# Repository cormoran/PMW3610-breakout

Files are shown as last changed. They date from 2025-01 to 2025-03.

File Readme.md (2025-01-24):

My PMW3610 breakout board collections and kicad library

- [V1](kicad_projects/PMW3610-breakout-v1/Readme.md)
  - Designed to minimize 1 side length (14mm x 21mm)
- [V2](kicad_projects/PMW3610-breakout-v2/Readme.md)
  - Designed to minimize width + height (17.6mm x 16.6mm)
  - Designed for 1 layer PCB assembly
  - 1.8V support by default. 3.6V support by manually soldering LDO.
- [V3](kicad_projects/PMW3610-breakout-v3/Readme.md) (I've not assembled yet!)
  - Designed to minimize width + height (17.6mm x 16.6mm)
  - Designed for 1 layer PCB assembly
  - 3.6V support by default. 1.8V support by removing LDO.

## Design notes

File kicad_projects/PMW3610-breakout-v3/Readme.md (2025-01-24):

## PMW3610 breakout board (v3)

I've not assembled this design yet. Functionality is not confirmed yet!

動作未確認

Features

- width = 17.6mm
- height = 16.6mm
- Designed for 100% 1-layer PCB assembly
- 3.6V support by default
- 1.8V support by removing LDO
- 6pin 5mm pitch FFC
- Test pad

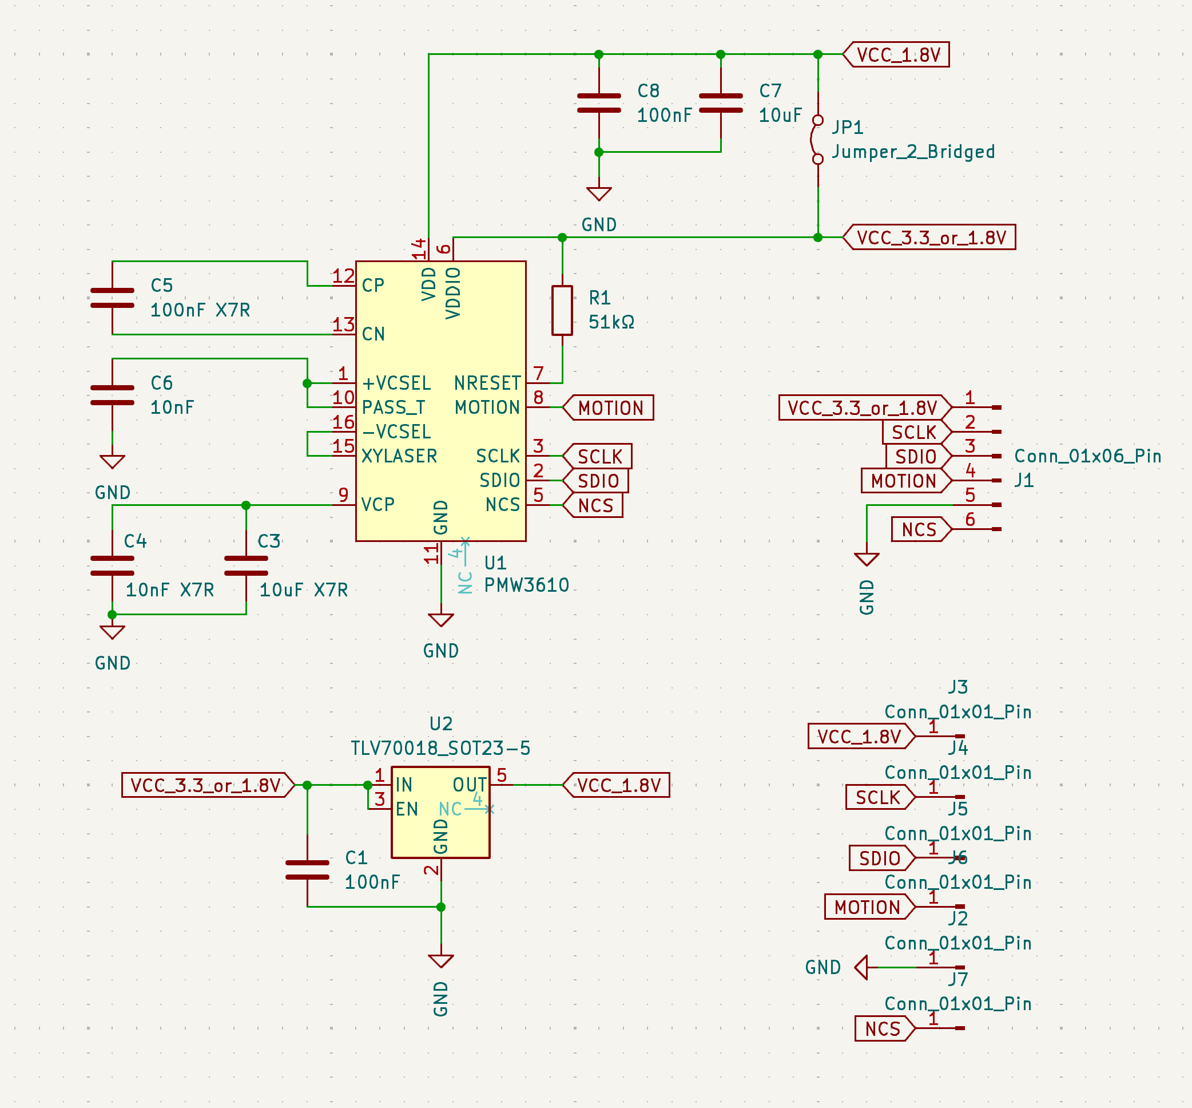
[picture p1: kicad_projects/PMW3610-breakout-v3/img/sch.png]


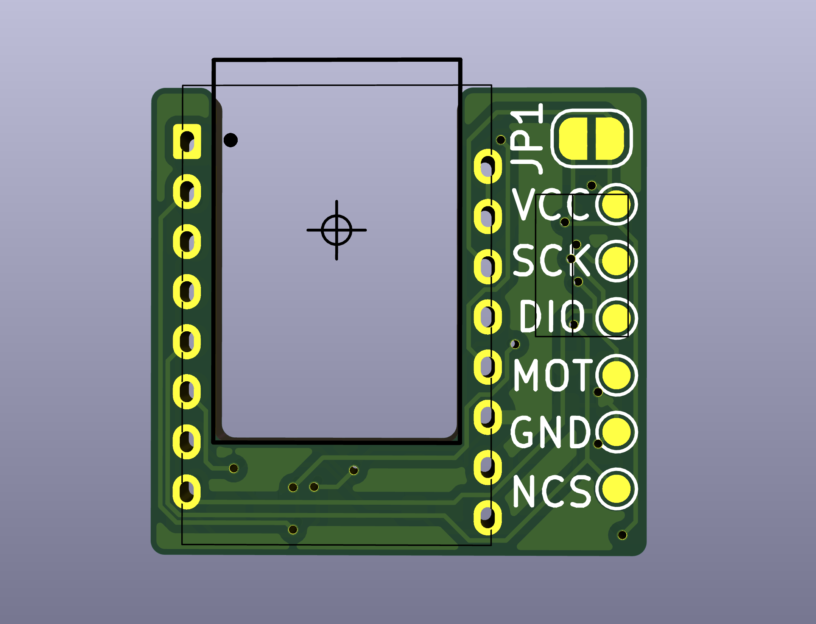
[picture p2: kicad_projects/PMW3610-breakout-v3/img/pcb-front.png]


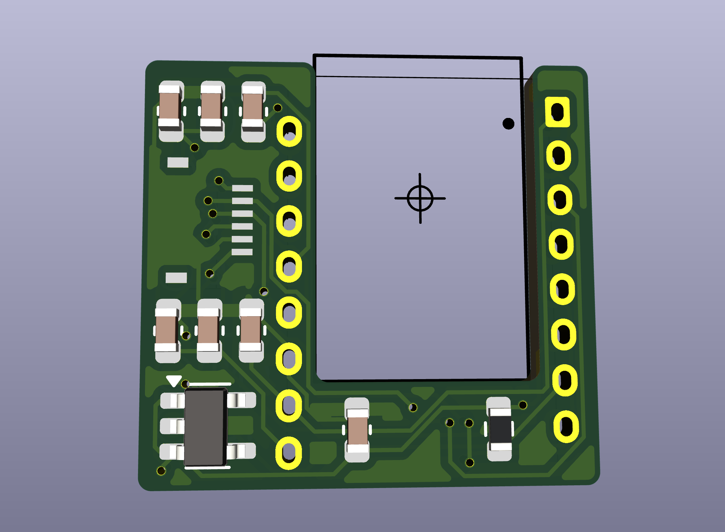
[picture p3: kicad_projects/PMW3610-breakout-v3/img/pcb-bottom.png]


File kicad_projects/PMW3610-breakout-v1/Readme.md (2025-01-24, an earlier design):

## PMW3610 breakout board (v1)

Features

- width = **14mm** (by cutting mounting holes)
- height = 21mm (by cutting mounting holes)
- 3.6V support
- 6pin 5mm pitch FFC

Problems

- Requires high manual soldering skills
- Unstable due to LDO's poor transient response?
  - It got stable by replacing C2 to 10uF in my case

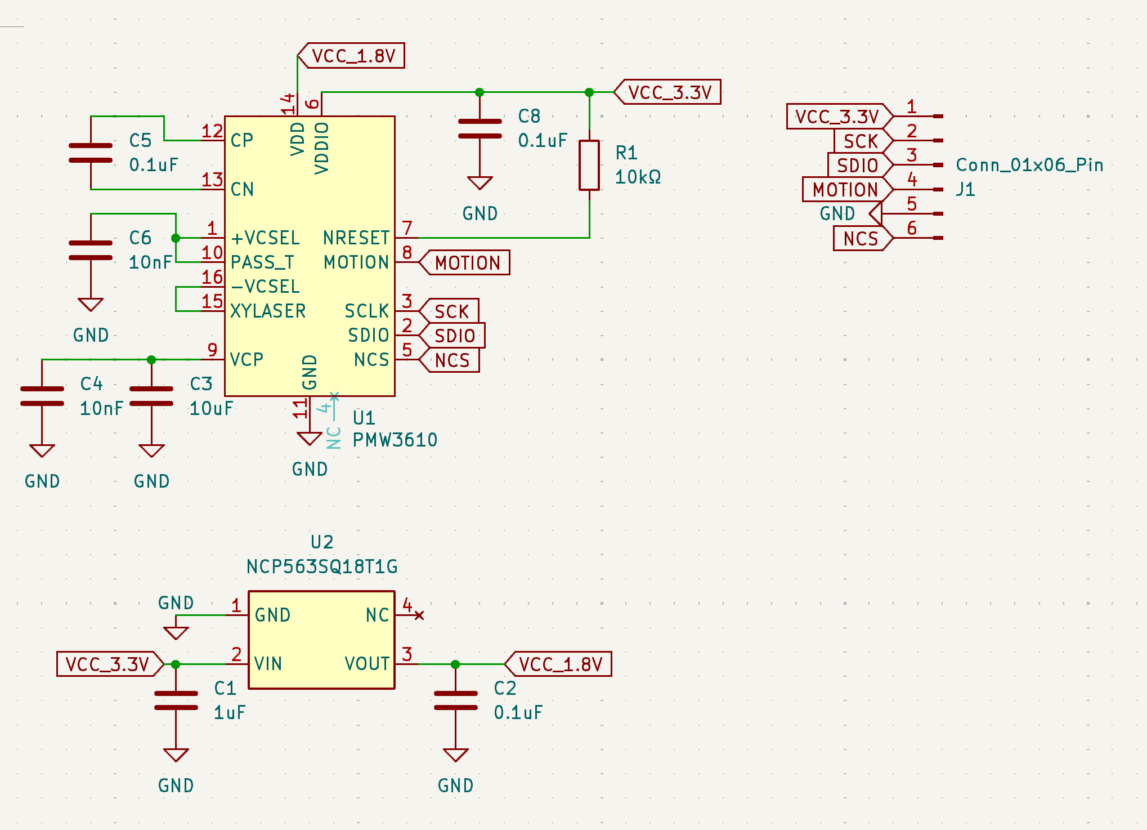
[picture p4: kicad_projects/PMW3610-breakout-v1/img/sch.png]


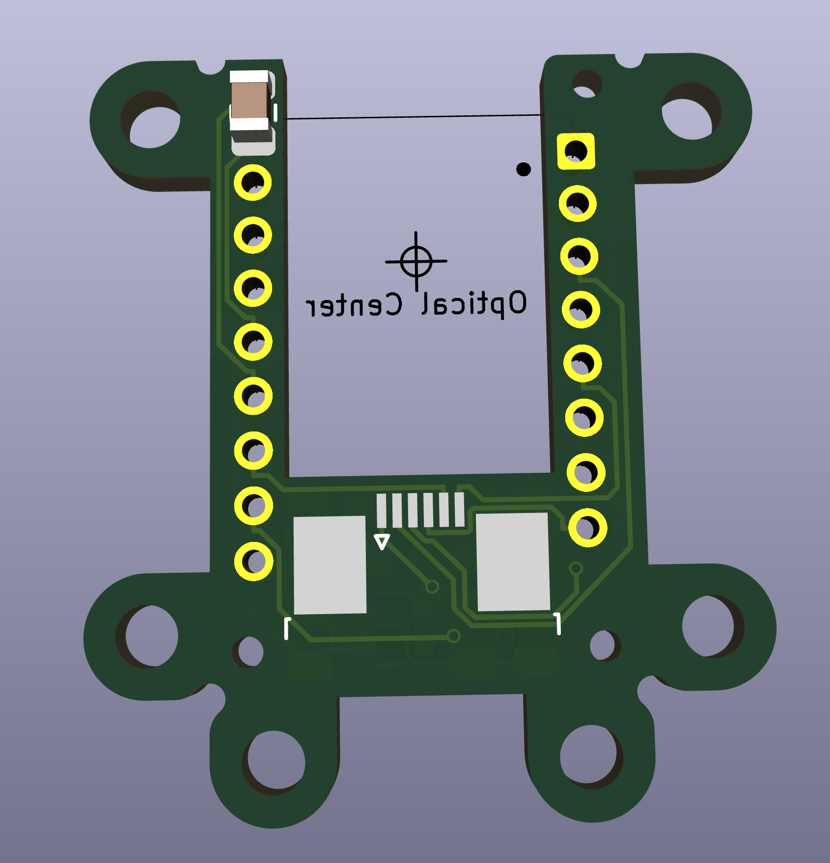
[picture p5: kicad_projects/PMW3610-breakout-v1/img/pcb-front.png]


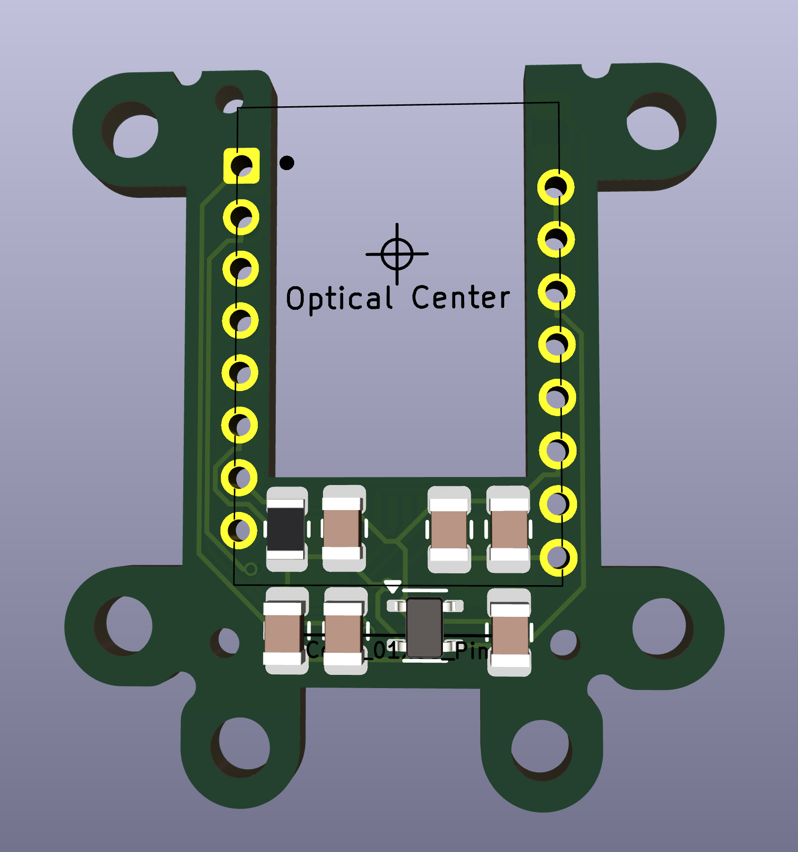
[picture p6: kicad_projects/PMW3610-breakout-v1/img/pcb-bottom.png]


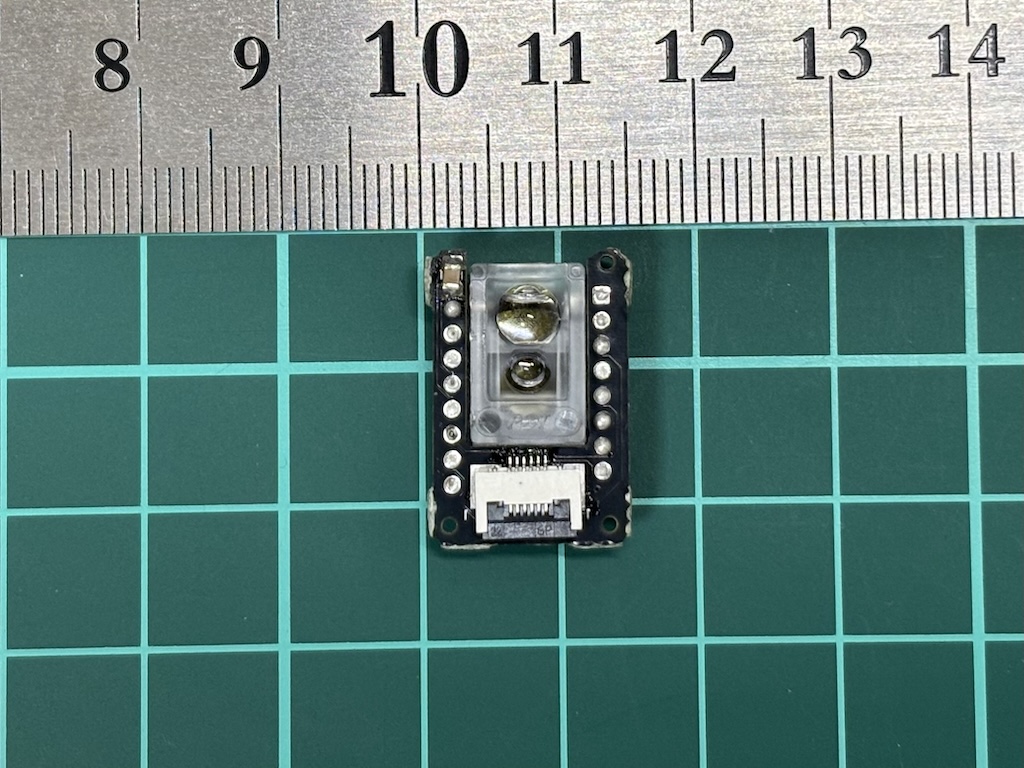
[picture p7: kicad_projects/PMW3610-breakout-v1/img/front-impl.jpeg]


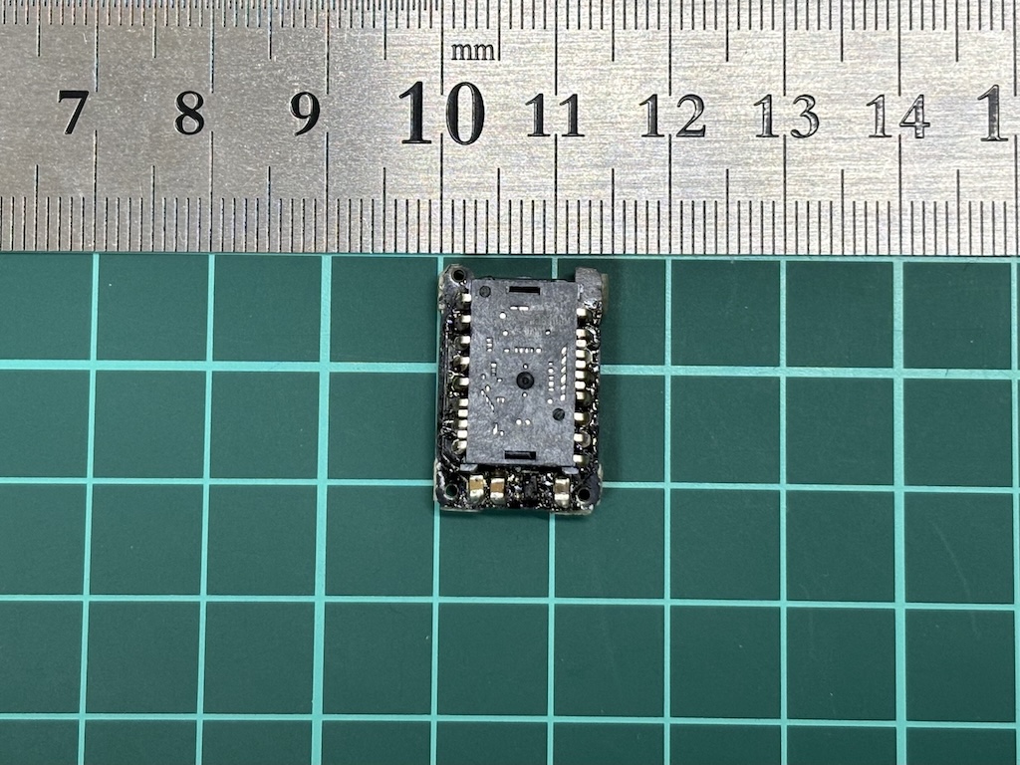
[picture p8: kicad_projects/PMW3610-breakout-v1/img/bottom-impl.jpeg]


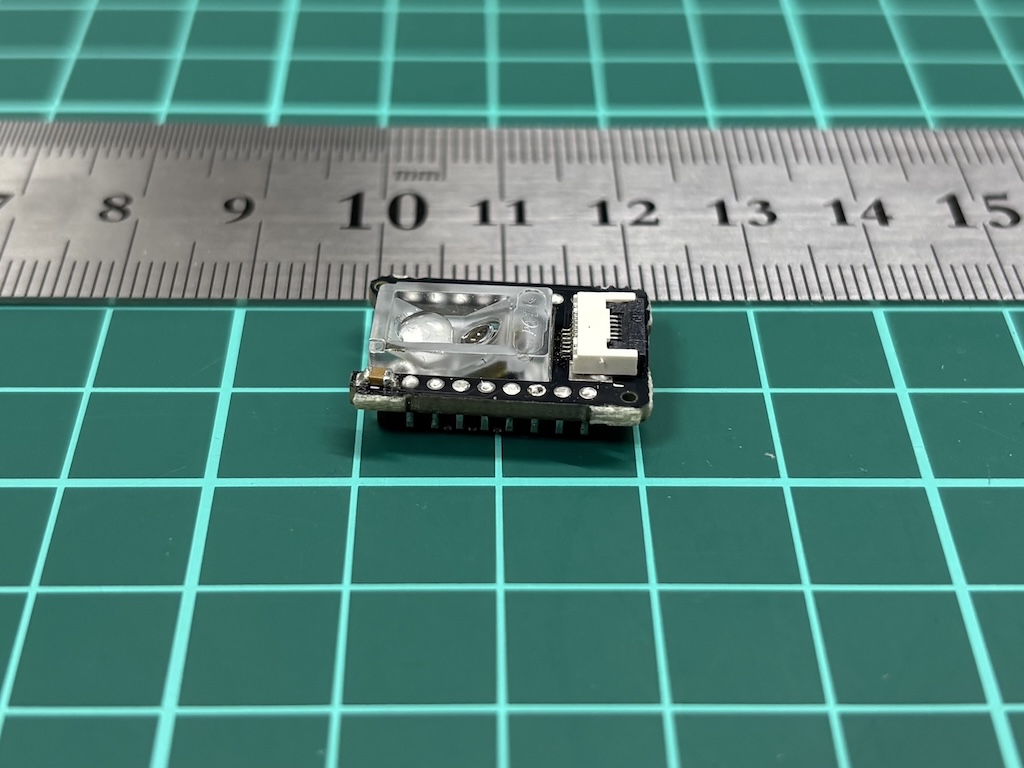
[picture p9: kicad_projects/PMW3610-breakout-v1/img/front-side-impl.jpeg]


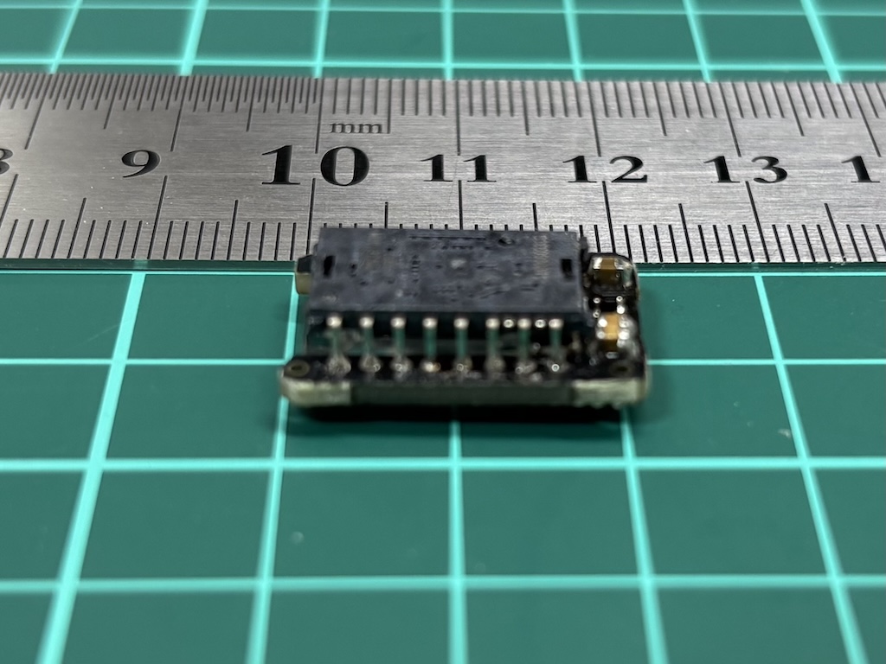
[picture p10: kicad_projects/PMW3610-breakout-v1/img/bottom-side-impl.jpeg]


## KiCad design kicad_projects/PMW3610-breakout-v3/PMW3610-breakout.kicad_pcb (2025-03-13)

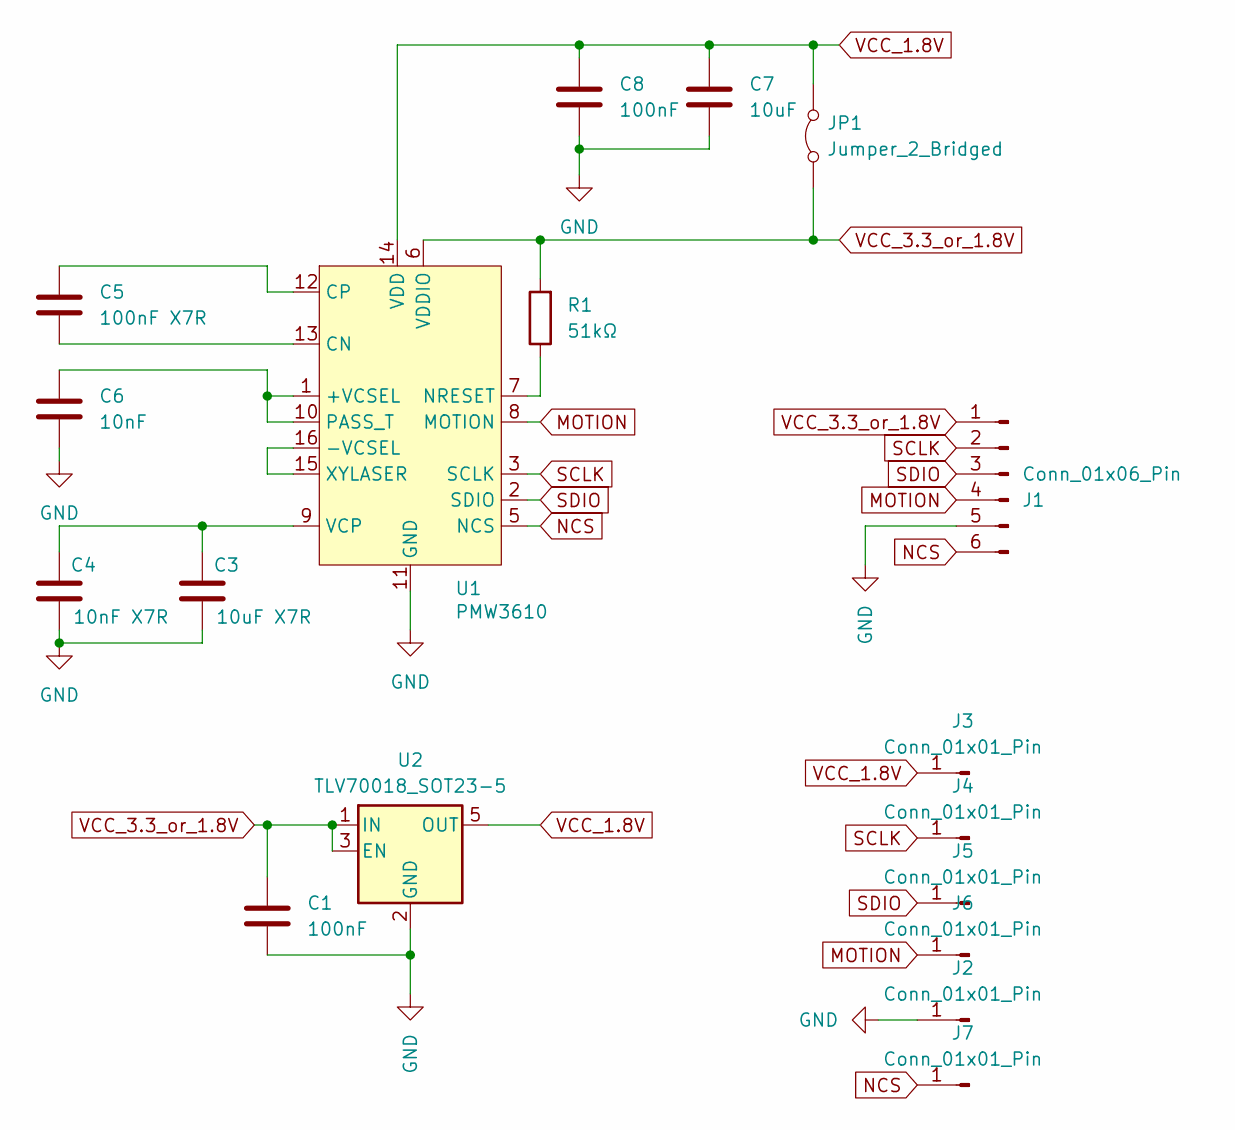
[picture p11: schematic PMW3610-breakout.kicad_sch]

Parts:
C1, C8: 100nF; C_0603_1608Metric; LCSC C14663
C3: 10uF X7R; C_0603_1608Metric; LCSC C19702
C4: 10nF X7R; C_0603_1608Metric; LCSC C57112
C5: 100nF X7R; C_0603_1608Metric; LCSC C14663
C6: 10nF; C_0603_1608Metric; LCSC C57112
C7: 10uF; C_0603_1608Metric; LCSC C19702
J1: Conn_01x06_Pin; JUSHUO-AFH34-S06FIA-1H; LCSC C5139821
J2, J3, J4, J5, J6, J7: Conn_01x01_Pin; TestPoint_Pad_D1.0mm
JP1: Jumper_2_Bridged; SolderJumper-2_P1.3mm_Open_RoundedPad1.0x1.5mm
R1: 51kΩ; R_0603_1608Metric; LCSC C23196
U1: PMW3610; PMW3610DM-SUDU 16Pin
U2: TLV70018_SOT23-5; SOT-23-5

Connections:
GND: C1.2, C3.2, C4.2, C6.2, C7.2, C8.2, J1.5, J2.1, U1.11 (GND), U2.2 (GND)
MOTION: J1.4, J6.1, U1.8 (MOTION)
NCS: J1.6, J7.1, U1.5 (NCS)
unnamed: C6.1, U1.1 (+VCSEL), U1.10 (PASS_T)
unnamed: U1.15 (XYLASER), U1.16 (-VCSEL)
unnamed: C5.2, U1.13 (CN)
unnamed: C5.1, U1.12 (CP)
unnamed: R1.1, U1.7 (NRESET)
unnamed: C3.1, C4.1, U1.9 (VCP)
SCLK: J1.2, J4.1, U1.3 (SCLK)
SDIO: J1.3, J5.1, U1.2 (SDIO)
VCC_1.8V: C7.1, C8.1, J3.1, JP1.2 (B), U1.14 (VDD), U2.5 (OUT)
VCC_3.3_or_1.8V: C1.1, J1.1, JP1.1 (A), R1.2, U1.6 (VDDIO), U2.1 (IN), U2.3 (EN)

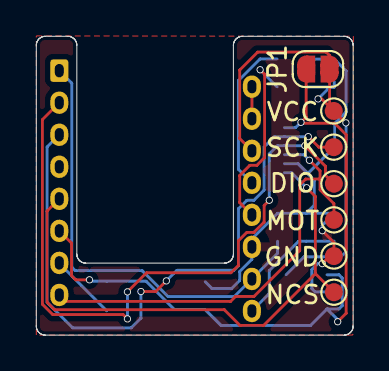
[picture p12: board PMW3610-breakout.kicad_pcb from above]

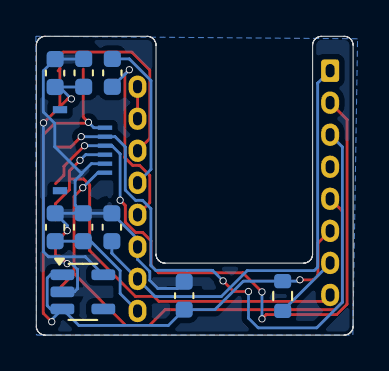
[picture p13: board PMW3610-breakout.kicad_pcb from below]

Board: 2 copper layers, 17.6 x 16.6 mm, 18 parts (10 on the bottom side), 13 nets.

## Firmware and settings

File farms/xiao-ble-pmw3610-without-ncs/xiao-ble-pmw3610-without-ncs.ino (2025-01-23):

// This code is based on https://github.com/inorichi/zmk-pmw3610-driver
#include "Adafruit_TinyUSB.h"

// xiao-ble pin assignment
// Note: to use NFC2 as GPIO, you need to set `-DCONFIG_NFCT_PINS_AS_GPIOS` to
// xiaonRF52840.build.extra_flags in board definition
//       e.g. For Mac,
//       /Users/<user>/Library/Arduino15/packages/Seeeduino/hardware/nrf52/1.1.8/boards.txt
//            Change corresponding line to
//            `xiaonRF52840.build.extra_flags=-DNRF52840_XXAA -DCONFIG_NFCT_PINS_AS_GPIOS {build.flags.usb}`

#define SCLK A5
#define SDIO A4
#define MOTION PIN_NFC2
// #define NCS // not used

/* Sensor registers (addresses) */
#define PMW3610_REG_PRODUCT_ID 0x00
#define PMW3610_REG_REVISION_ID 0x01
#define PMW3610_REG_MOTION 0x02
#define PMW3610_REG_DELTA_X_L 0x03
#define PMW3610_REG_DELTA_Y_L 0x04
#define PMW3610_REG_DELTA_XY_H 0x05
#define PMW3610_REG_SQUAL 0x06
#define PMW3610_REG_SHUTTER_HIGHER 0x07
#define PMW3610_REG_SHUTTER_LOWER 0x08
#define PMW3610_REG_PIX_MAX 0x09
#define PMW3610_REG_PIX_AVG 0x0A
#define PMW3610_REG_PIX_MIN 0x0B

#define PMW3610_REG_CRC0 0x0C
#define PMW3610_REG_CRC1 0x0D
#define PMW3610_REG_CRC2 0x0E
#define PMW3610_REG_CRC3 0x0F
#define PMW3610_REG_SELF_TEST 0x10

#define PMW3610_REG_PERFORMANCE 0x11
#define PMW3610_REG_MOTION_BURST 0x12

#define PMW3610_REG_RUN_DOWNSHIFT 0x1B
#define PMW3610_REG_REST1_PERIOD 0x1C
#define PMW3610_REG_REST1_DOWNSHIFT 0x1D
#define PMW3610_REG_REST2_PERIOD 0x1E
#define PMW3610_REG_REST2_DOWNSHIFT 0x1F
#define PMW3610_REG_REST3_PERIOD 0x20
#define PMW3610_REG_OBSERVATION 0x2D

#define PMW3610_REG_PIXEL_GRAB 0x35
#define PMW3610_REG_FRAME_GRAB 0x36

#define PMW3610_REG_POWER_UP_RESET 0x3A
#define PMW3610_REG_SHUTDOWN 0x3B

#define PMW3610_REG_SPI_CLK_ON_REQ 0x41
#define PMW3610_REG_RES_STEP 0x85

#define PMW3610_REG_NOT_REV_ID 0x3E
#define PMW3610_REG_NOT_PROD_ID 0x3F

#define PMW3610_REG_PRBS_TEST_CTL 0x47
#define PMW3610_REG_SPI_PAGE0 0x7F
#define PMW3610_REG_VCSEL_CTL 0x9E
#define PMW3610_REG_LSR_CONTROL 0x9F
#define PMW3610_REG_SPI_PAGE1 0xFF

/* Sensor identification values */
#define PMW3610_PRODUCT_ID 0x3E

/* Power-up register commands */
#define PMW3610_POWERUP_CMD_RESET 0x5A
#define PMW3610_POWERUP_CMD_WAKEUP 0x96

/* spi clock enable/disable commands */
#define PMW3610_SPI_CLOCK_CMD_ENABLE 0xBA
#define PMW3610_SPI_CLOCK_CMD_DISABLE 0xB5

/* write command bit position */
#define BIT(i) (1 << i)
#define PMW3610_WRITE_BIT BIT(7)

#define PMW3610_MOTION_MOT BIT(7) #1 : motion occured
#define PMW3610_MOTION_OVF BIT(4) #1 : motion overflow

#define TOINT16(val, bits) (((struct { int16_t value : bits; }){val}).value)

static uint8_t reg_read(uint8_t reg_address) {
    pinMode(SDIO, OUTPUT);
    for (int8_t i = 7; i >= 0; i--) {
        digitalWrite(SCLK, 0);
        digitalWrite(SDIO, reg_address & BIT(i));
        delayMicroseconds(1);
        digitalWrite(SCLK, 1);
        delayMicroseconds(1);
    }
    pinMode(SDIO, INPUT);
    delayMicroseconds(4);
    uint8_t r = 0;
    for (int8_t i = 7; i >= 0; i--) {
        digitalWrite(SCLK, 0);
        delayMicroseconds(1);
        digitalWrite(SCLK, 1);
        delayMicroseconds(1);
        r |= digitalRead(SDIO) << i;
    }
    delayMicroseconds(10);
    return r;
}

static void _reg_write(uint8_t reg_address, uint8_t data) {
    reg_address |= PMW3610_WRITE_BIT;

    pinMode(SDIO, OUTPUT);
    for (int8_t i = 7; i >= 0; i--) {
        digitalWrite(SCLK, 0);
        digitalWrite(SDIO, reg_address & BIT(i));
        delayMicroseconds(1);
        digitalWrite(SCLK, 1);
        delayMicroseconds(1);
    }
    for (int8_t i = 7; i >= 0; i--) {
        digitalWrite(SCLK, 0);
        digitalWrite(SDIO, data & BIT(i));
        delayMicroseconds(1);
        digitalWrite(SCLK, 1);
        delayMicroseconds(1);
    }
    delayMicroseconds(4);
}

static void reg_write(uint8_t reg_address, uint8_t data) {
    _reg_write(PMW3610_REG_SPI_CLK_ON_REQ, PMW3610_SPI_CLOCK_CMD_ENABLE);
    _reg_write(reg_address, data);
    _reg_write(PMW3610_REG_SPI_CLK_ON_REQ, PMW3610_SPI_CLOCK_CMD_DISABLE);
}

// 200~3200, 1200 by default
static void set_cpi(uint32_t cpi) {
    uint8_t value = cpi / 200;
    reg_write(PMW3610_REG_SPI_PAGE0, 0xFF);
    reg_write(PMW3610_REG_RES_STEP, value);
    reg_write(PMW3610_REG_SPI_PAGE1, 0x00);
}

void setup() {
    pinMode(VBAT_ENABLE, OUTPUT);
    digitalWrite(VBAT_ENABLE, 0);
    pinMode(LED_RED, OUTPUT);
    pinMode(LED_GREEN, OUTPUT);
    pinMode(LED_BLUE, OUTPUT);

    pinMode(SCLK, OUTPUT);
    pinMode(SDIO, OUTPUT);
    pinMode(MOTION, INPUT);

    Serial.begin(38400);
    delay(5000);
    init_pmw3610();
}

void init_pmw3610() {
    reg_write(PMW3610_REG_POWER_UP_RESET, PMW3610_POWERUP_CMD_RESET);
    delay(50);

    reg_write(PMW3610_REG_OBSERVATION, 0x00);
    delay(10);
    uint8_t observation = reg_read(0x2D);
    if ((observation & 0x0F) != 0x0F) {
        Serial.println("Observation failure");
    } else {
        Serial.println("Observation OK");
    }

    reg_read(PMW3610_REG_MOTION);
    reg_read(PMW3610_REG_DELTA_X_L);
    reg_read(PMW3610_REG_DELTA_Y_L);
    reg_read(PMW3610_REG_DELTA_XY_H);

    // Read product ID multiple times to ensure sensor is stably working.
    for (int i = 0; i < 10; i++) {
        Serial.write("Product Id = ");
        Serial.println(reg_read(PMW3610_REG_PRODUCT_ID));
        Serial.write("Revision Id = ");
        Serial.println(reg_read(PMW3610_REG_REVISION_ID));
    }

    reg_write(PMW3610_REG_PERFORMANCE,
              0x0d);  // normal operation, 4ms, 4ms, 4ms
    // Time after which sensor goes from RUN to REST1 mode.
    reg_write(PMW3610_REG_RUN_DOWNSHIFT,
              0x04);  // 128ms (unit: pos-rate (4ms) * 8 = 32ms)
    reg_write(PMW3610_REG_REST1_PERIOD, 0x04);  // 40ms (unit: 10ms)
    reg_write(PMW3610_REG_REST1_DOWNSHIFT,
              0x0f);  // (unit: 16 * Rest1_sample_period (above, 40ms))

    set_cpi(200);
}

void loop() {
    if (Serial.available()) {
        String s = Serial.readString();
        if (s.startsWith("reset")) {
            init_pmw3610();
        }
    }
    if (digitalRead(MOTION) == 0) {
        uint8_t motion = reg_read(PMW3610_REG_MOTION);
        if (motion & BIT(7)) {
            uint16_t delta_x_l  = reg_read(PMW3610_REG_DELTA_X_L);
            uint16_t delta_y_l  = reg_read(PMW3610_REG_DELTA_Y_L);
            uint16_t delta_xy_h = reg_read(PMW3610_REG_DELTA_XY_H);
            // force-reset delta registers
            // reg_write(PMW3610_REG_MOTION, 0x09);
            int16_t delta_x =
                TOINT16(delta_x_l + ((delta_xy_h & 0xF0) << 4), 12);
            int16_t delta_y =
                TOINT16(delta_y_l + ((delta_xy_h & 0x0F) << 8), 12);
            Serial.print("M=");
            for (int i = 7; i >= 0; i--) {
                Serial.print((motion & BIT(i)) ? "1" : "0");
            }
            Serial.print(" dx_l =");
            for (int i = 7; i >= 0; i--) {
                Serial.print((delta_x_l & BIT(i)) ? "1" : "0");
            }
            Serial.print(" dy_l =");
            for (int i = 7; i >= 0; i--) {
                Serial.print((delta_y_l & BIT(i)) ? "1" : "0");
            }
            Serial.print(" dxy_h =");
            for (int i = 7; i >= 0; i--) {
                Serial.print((delta_xy_h & BIT(i)) ? "1" : "0");
            }
            Serial.printf(", x = %d y = %d\n", delta_x, delta_y);
        } else {
            Serial.print("M=");
            for (int i = 7; i >= 0; i--) {
                Serial.print((motion & BIT(i)) ? "1" : "0");
            }
            Serial.println();
        }
    }
}

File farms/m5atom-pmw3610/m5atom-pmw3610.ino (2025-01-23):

// This code is based on https://github.com/inorichi/zmk-pmw3610-driver
#include <M5Atom.h>

// M5Atom pin assignment

#define SCK G22
#define SDIO G19
#define MOTION G23
#define NCS G33

// --

#define T_NCS_SCLK 1     /* 120 ns (rounded to 1us) */
#define T_SCLK_NCS_WR 10 /* 10 us */
#define T_SRAD 4         /* 4 us */
#define T_SRAD_MOTBR 4   /* same as T_SRAD */
#define T_SRX 1          /* 250 ns (rounded to 1 us) */
#define T_SWX 30         /* SWW: 30 us, SWR: 20 us */
#define T_BEXIT 1        /* 250 ns (rounded to 1us)*/

/* Sensor registers (addresses) */
#define PMW3610_REG_PRODUCT_ID 0x00
#define PMW3610_REG_REVISION_ID 0x01
#define PMW3610_REG_MOTION 0x02
#define PMW3610_REG_DELTA_X_L 0x03
#define PMW3610_REG_DELTA_Y_L 0x04
#define PMW3610_REG_DELTA_XY_H 0x05
#define PMW3610_REG_SQUAL 0x06
#define PMW3610_REG_SHUTTER_HIGHER 0x07
#define PMW3610_REG_SHUTTER_LOWER 0x08
#define PMW3610_REG_PIX_MAX 0x09
#define PMW3610_REG_PIX_AVG 0x0A
#define PMW3610_REG_PIX_MIN 0x0B

#define PMW3610_REG_CRC0 0x0C
#define PMW3610_REG_CRC1 0x0D
#define PMW3610_REG_CRC2 0x0E
#define PMW3610_REG_CRC3 0x0F
#define PMW3610_REG_SELF_TEST 0x10

#define PMW3610_REG_PERFORMANCE 0x11
#define PMW3610_REG_MOTION_BURST 0x12

#define PMW3610_REG_RUN_DOWNSHIFT 0x1B
#define PMW3610_REG_REST1_PERIOD 0x1C
#define PMW3610_REG_REST1_DOWNSHIFT 0x1D
#define PMW3610_REG_REST2_PERIOD 0x1E
#define PMW3610_REG_REST2_DOWNSHIFT 0x1F
#define PMW3610_REG_REST3_PERIOD 0x20
#define PMW3610_REG_OBSERVATION 0x2D

#define PMW3610_REG_PIXEL_GRAB 0x35
#define PMW3610_REG_FRAME_GRAB 0x36

#define PMW3610_REG_POWER_UP_RESET 0x3A
#define PMW3610_REG_SHUTDOWN 0x3B

#define PMW3610_REG_SPI_CLK_ON_REQ 0x41
#define PMW3610_REG_RES_STEP 0x85

#define PMW3610_REG_NOT_REV_ID 0x3E
#define PMW3610_REG_NOT_PROD_ID 0x3F

#define PMW3610_REG_PRBS_TEST_CTL 0x47
#define PMW3610_REG_SPI_PAGE0 0x7F
#define PMW3610_REG_VCSEL_CTL 0x9E
#define PMW3610_REG_LSR_CONTROL 0x9F
#define PMW3610_REG_SPI_PAGE1 0xFF

/* Sensor identification values */
#define PMW3610_PRODUCT_ID 0x3E

/* Power-up register commands */
#define PMW3610_POWERUP_CMD_RESET 0x5A
#define PMW3610_POWERUP_CMD_WAKEUP 0x96

/* spi clock enable/disable commands */
#define PMW3610_SPI_CLOCK_CMD_ENABLE 0xBA
#define PMW3610_SPI_CLOCK_CMD_DISABLE 0xB5

/* write command bit position */
// #define BIT(i) (1 << i)
#define PMW3610_WRITE_BIT BIT(7)

CRGB dispColor(uint8_t g, uint8_t r, uint8_t b) {
    return (CRGB)((g << 16) | (r << 8) | b);
}

static void set_cs(bool cs) {
    if (!cs) {
        delayMicroseconds(T_NCS_SCLK);
    }
    digitalWrite(NCS, cs ? 0 : 1);
    if (cs) {
        delayMicroseconds(T_NCS_SCLK);
    }
}

static uint8_t reg_read(uint8_t reg_address) {
    set_cs(true);
    pinMode(SDIO, OUTPUT);
    for (int8_t i = 7; i >= 0; i--) {
        digitalWrite(SCK, 0);
        delayMicroseconds(1);
        digitalWrite(SDIO, reg_address & BIT(i));
        digitalWrite(SCK, 1);
        delayMicroseconds(5);
    }
    pinMode(SDIO, INPUT);
    delayMicroseconds(T_SRAD);
    delay(10);
    uint8_t r = 0;
    for (int8_t i = 7; i >= 0; i--) {
        digitalWrite(SCK, 0);
        delayMicroseconds(1);
        digitalWrite(SCK, 1);
        r |= digitalRead(SDIO) << i;
        delayMicroseconds(1);
    }
    set_cs(false);
    delayMicroseconds(T_SRX);
    return r;
}

static void _reg_write(uint8_t reg_address, uint8_t data) {
    reg_address |= PMW3610_WRITE_BIT;

    set_cs(true);
    pinMode(SDIO, OUTPUT);
    for (int8_t i = 7; i >= 0; i--) {
        digitalWrite(SCK, 0);
        digitalWrite(SDIO, reg_address & BIT(i));
        delayMicroseconds(1);
        digitalWrite(SCK, 1);
        delayMicroseconds(5);
    }
    for (int8_t i = 7; i >= 0; i--) {
        digitalWrite(SCK, 0);
        digitalWrite(SDIO, data & BIT(i));
        delayMicroseconds(1);
        digitalWrite(SCK, 1);
        delayMicroseconds(5);
    }
    delayMicroseconds(T_SCLK_NCS_WR);
    set_cs(false);
    delayMicroseconds(T_SWX);
}

static void reg_write(uint8_t reg_address, uint8_t data) {
    _reg_write(PMW3610_REG_SPI_CLK_ON_REQ, PMW3610_SPI_CLOCK_CMD_ENABLE);
    _reg_write(reg_address, data);
    _reg_write(PMW3610_REG_SPI_CLK_ON_REQ, PMW3610_SPI_CLOCK_CMD_DISABLE);
}

struct MotionData {
    bool motion;
    int16_t dx;
    int16_t dy;
};

void setup() {
    M5.begin(true, false, true);
    M5.dis.drawpix(0, dispColor(0, 0, 0));
    pinMode(SCK, OUTPUT);
    pinMode(SDIO, OUTPUT);
    pinMode(NCS, OUTPUT);
    pinMode(MOTION, INPUT);

    // Serial.begin(38400);
    init_pmw3610();
}

void init_pmw3610() {
    set_cs(false);
    set_cs(true);
    reg_write(PMW3610_REG_POWER_UP_RESET, PMW3610_POWERUP_CMD_RESET);

    delay(10);
    reg_write(PMW3610_REG_OBSERVATION, 0x00);

    delay(200);
    uint8_t obs = reg_read(PMW3610_REG_OBSERVATION);
    if ((obs & 0x0F) != 0x0F) {
        Serial.println("observation is wrong");
        return;
    }
    Serial.write("Product Id = ");
    Serial.println(reg_read(PMW3610_REG_PRODUCT_ID));
    Serial.write("Revision Id = ");
    Serial.println(reg_read(PMW3610_REG_REVISION_ID));

    delay(50);

    reg_read(PMW3610_REG_MOTION);
    reg_read(PMW3610_REG_DELTA_X_L);
    reg_read(PMW3610_REG_DELTA_Y_L);
    reg_read(PMW3610_REG_DELTA_XY_H);
}

void loop() {
    uint8_t motion = reg_read(PMW3610_REG_MOTION);
    if (motion & BIT(7)) {
        Serial.write("Motion = ");
        Serial.println(motion);
        Serial.write("delta_x = ");
        Serial.println(reg_read(PMW3610_REG_DELTA_X_L));
        Serial.write("delta_y = ");
        Serial.println(reg_read(PMW3610_REG_DELTA_Y_L));
        Serial.write("delta_xy = ");
        Serial.println(reg_read(PMW3610_REG_DELTA_XY_H));
    }
    delay(1000);
    M5.dis.drawpix(0, dispColor(255, 0, 0));
    delay(1000);
    M5.dis.drawpix(0, dispColor(0, 255, 0));
}

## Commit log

2025-01-23 Import kicad_library private repo
2025-01-23 Import PMW3610-breakout from private repo
    [PMW3610-breakout.kicad_pcb, PMW3610-breakout.kicad_sch, panelized.kicad_pcb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]
2025-01-23 Import sample arduino farms
2025-01-23 Remove GPS info from pictures and re-commit :( * Add readme * Add PMW3610-breakout-v1 old version PCB * Add Readme and pictures. Rename PMW3610-breakout to PMW3610-breakout-v2
    [PMW3610-breakout.kicad_pcb, PMW3610-breakout.kicad_sch, panelized.kicad_pcb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]
2025-01-24 Add v3 breakout which support 3.6V by default without additional SMT parts
    [PMW3610-breakout.kicad_pcb, PMW3610-breakout.kicad_sch]
2025-03-13 Fix missing wire in V3
    [PMW3610-breakout.kicad_pcb]
